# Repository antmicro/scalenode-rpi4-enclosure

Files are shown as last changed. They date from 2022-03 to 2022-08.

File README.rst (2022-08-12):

=========================
Scalenode RPi 4 enclosure
=========================

Copyright (c) 2022 `Antmicro <https://www.antmicro.com>`_

Overview
--------

This repository contains open hardware design files of the Raspberry Pi 4 cluster enclosure.

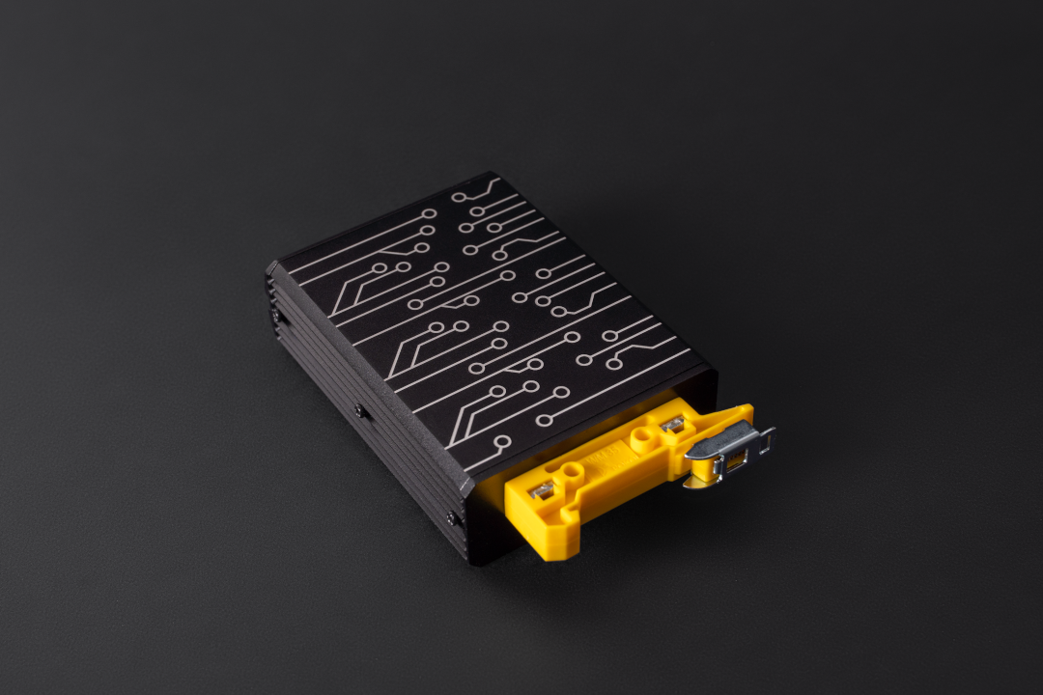
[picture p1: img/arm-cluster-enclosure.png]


It is designed to be a modular and stackable solution for an ARM cluster based on Raspberry Pi 4B. 
The design files are provided in a STEP file format.
The geometry of the metal body of the enclosure allows for machining with most of the CNC prototyping services.
The enclosure includes a translucent 3D-printable light guide which was optimized for SLA printing with translucent resins.

Repository structure
--------------------
The main repository directory contains 3D models of the enclosure assembly, a LICENSE and README.
The remaining files are stored in the following directories:

* ``pts`` - contains the project parts in separate files
* ``img`` - contains graphics for this README
* ``dwg`` - contains mechanical drawings
* ``csv`` - contains BOM

Key features
------------
* Passive cooling design
* DIN rail mount
* RGB LED indicator
* Modular and stackable
* 2U in a 19" rack cabinet
* Up to 56 units fit on a single floor of the rack cabinet

Mechanical outline
------------------

The enclosure provides passive cooling and was designed in a stackable form on a TH35 (DIN) rail.
There are multiple off-the-shelf DIN rail panel brackets available for 19" rack cabinets. 
The enclosure occupies 2U while installed in a rack cabinet.
Below there is a mechanical overview provided with outline dimensions provided in millimeters.

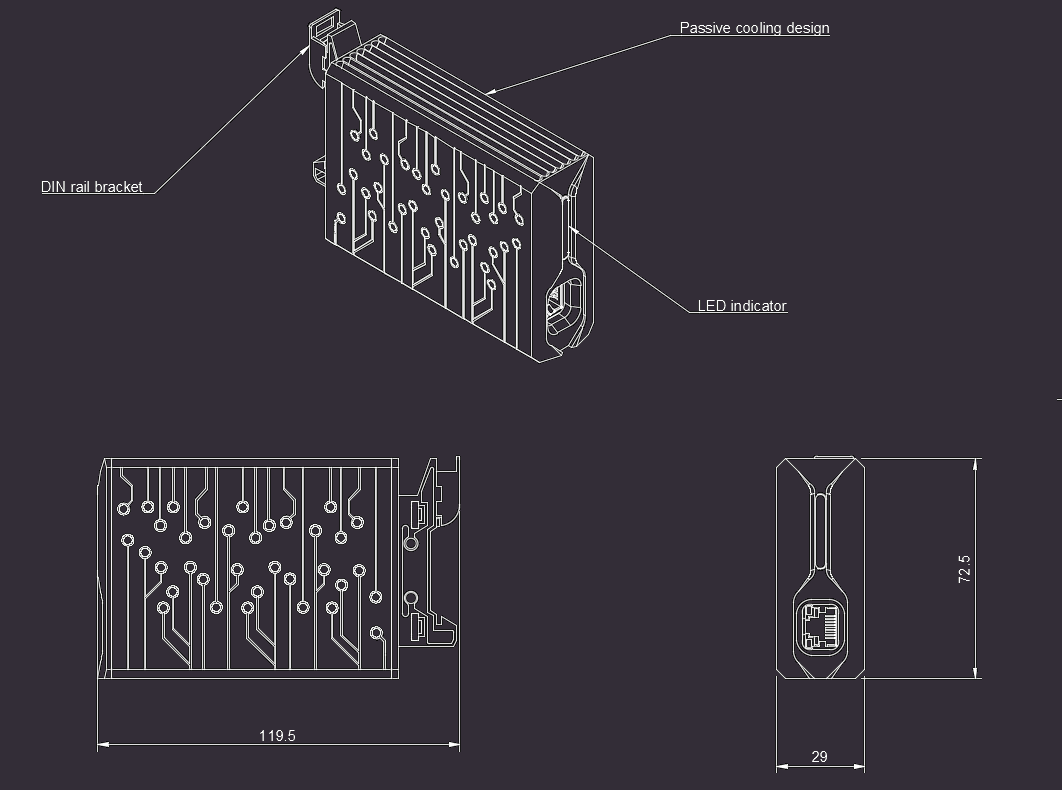
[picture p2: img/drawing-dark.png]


Assembly instructions
---------------------

A basic BOM is provided as a separate `CSV file <csv/rpi-enclosure-bom.csv>`_ to aid the component sourcing.
The assembly instructions below refer to the parts from that BOM.
The assembly includes a custom `RPi LED Flex PCB <https://github.com/antmicro/rpi-led-flex-board>`_ which has been released as an Open Source Hardware project in a separate repository.

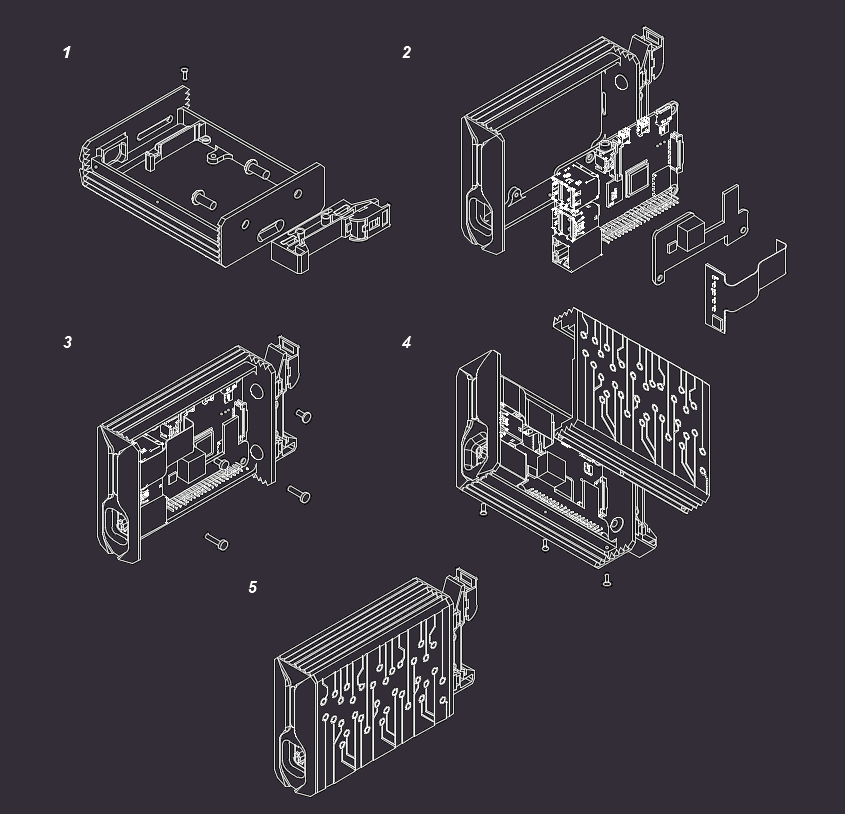
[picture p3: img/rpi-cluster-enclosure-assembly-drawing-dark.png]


#. Insert the 3D-printed RPi LED lightguide into the main case and fasten the bolt
   
   * Mount the WM-35 din clip with two bolts

#. Insert RPi LED indicator into the lightguide

   * Mount the UCTRONICS (`UC U6109 <https://www.uctronics.com/poe-hat-for-raspberry-pi-4-uctronics-mini-power-over-ethernet-expansion-board-for-raspberry-pi-4-b-3-b.html>`_) PoE hat on the Raspberry PI and put it in the main case
   * Insert FFC of the LED indicator into the camera connector (J3) located on the Raspberry Pi

#. Fasten Raspberry Pi and the PoE hat using M2.5 bolts

   * Apply some thermal paste to the processor and the DC/DC regulator on the PoE Hat

#. Put the cover on and press it down so that the paste evenly covers the surface of the ICs

   * Place the bolts in the holes on the bottom of the housing and tighten them gently
   
#. Insert an SD card to the Raspberry using a slot located under the DIN clip

#. Attach Ethernet cable connected to a PoE switch/injector and check if the RPi boots

License
=======

`Apache-2.0 <LICENSE>`_

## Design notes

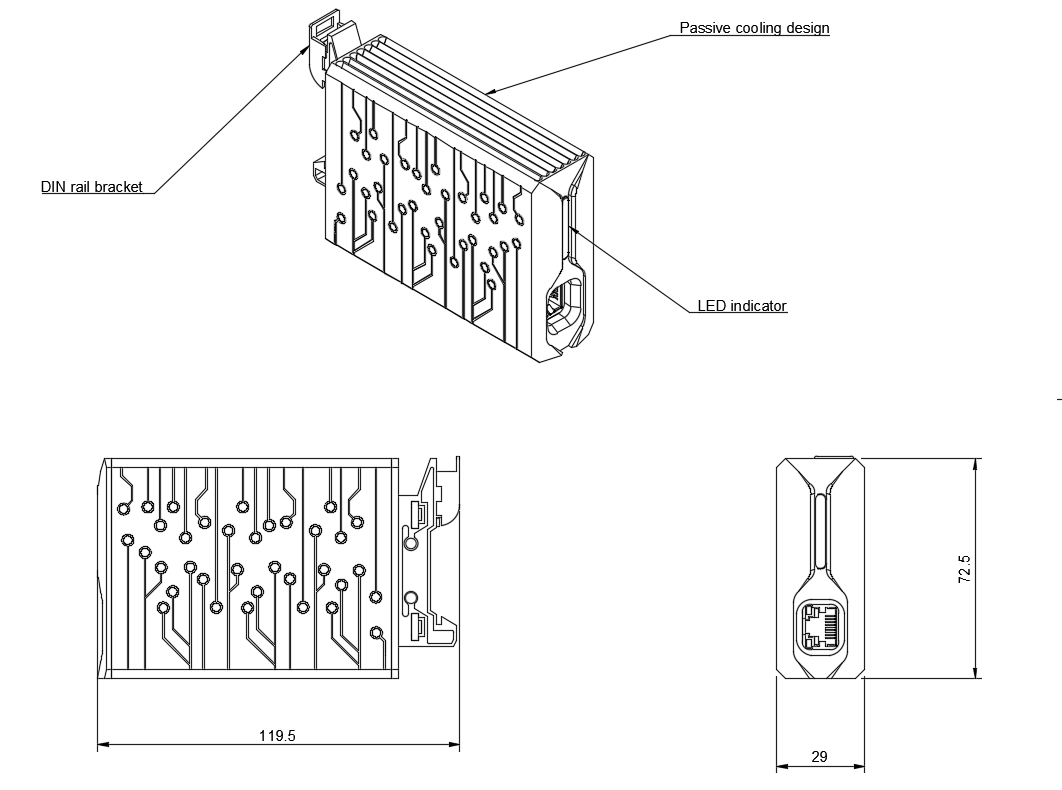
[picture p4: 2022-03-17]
img/drawing.png

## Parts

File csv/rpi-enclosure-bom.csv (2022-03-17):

Item | Description | Qty per unit
1 | RPi Enclosure | 1
2 | RPi LED lightguide | 1
3 | RPi LED Indicator | 1
4 | Raspberry Pi 4 B 8GB RAM 1.5GHz | 1
5 | PoE Hat UCTRONICS U6109 | 1
6 | WM-35 DIN clip | 1
7 | Enclosure fastening bolts(M1.6x5) | 3
8 | Lightguide fastening bolt (M1.6x5) | 1
9 | Poe Hat fastening bolts (M2.5x5) | 2
10 | RPi fastening bolts (M2.5x5) | 2
11 | DIN clip fastening bolts (M4x10) | 2
12 | PoE Hat standoff (2.7x03) | 2
13 | Thermal paste | 1g

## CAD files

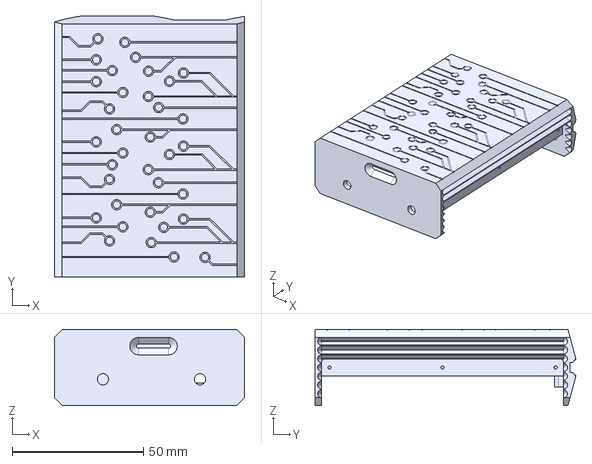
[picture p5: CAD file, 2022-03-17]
pts/rpi-cluster-enclosure-main-case.step
72.5 x 99.5 x 29.0 mm

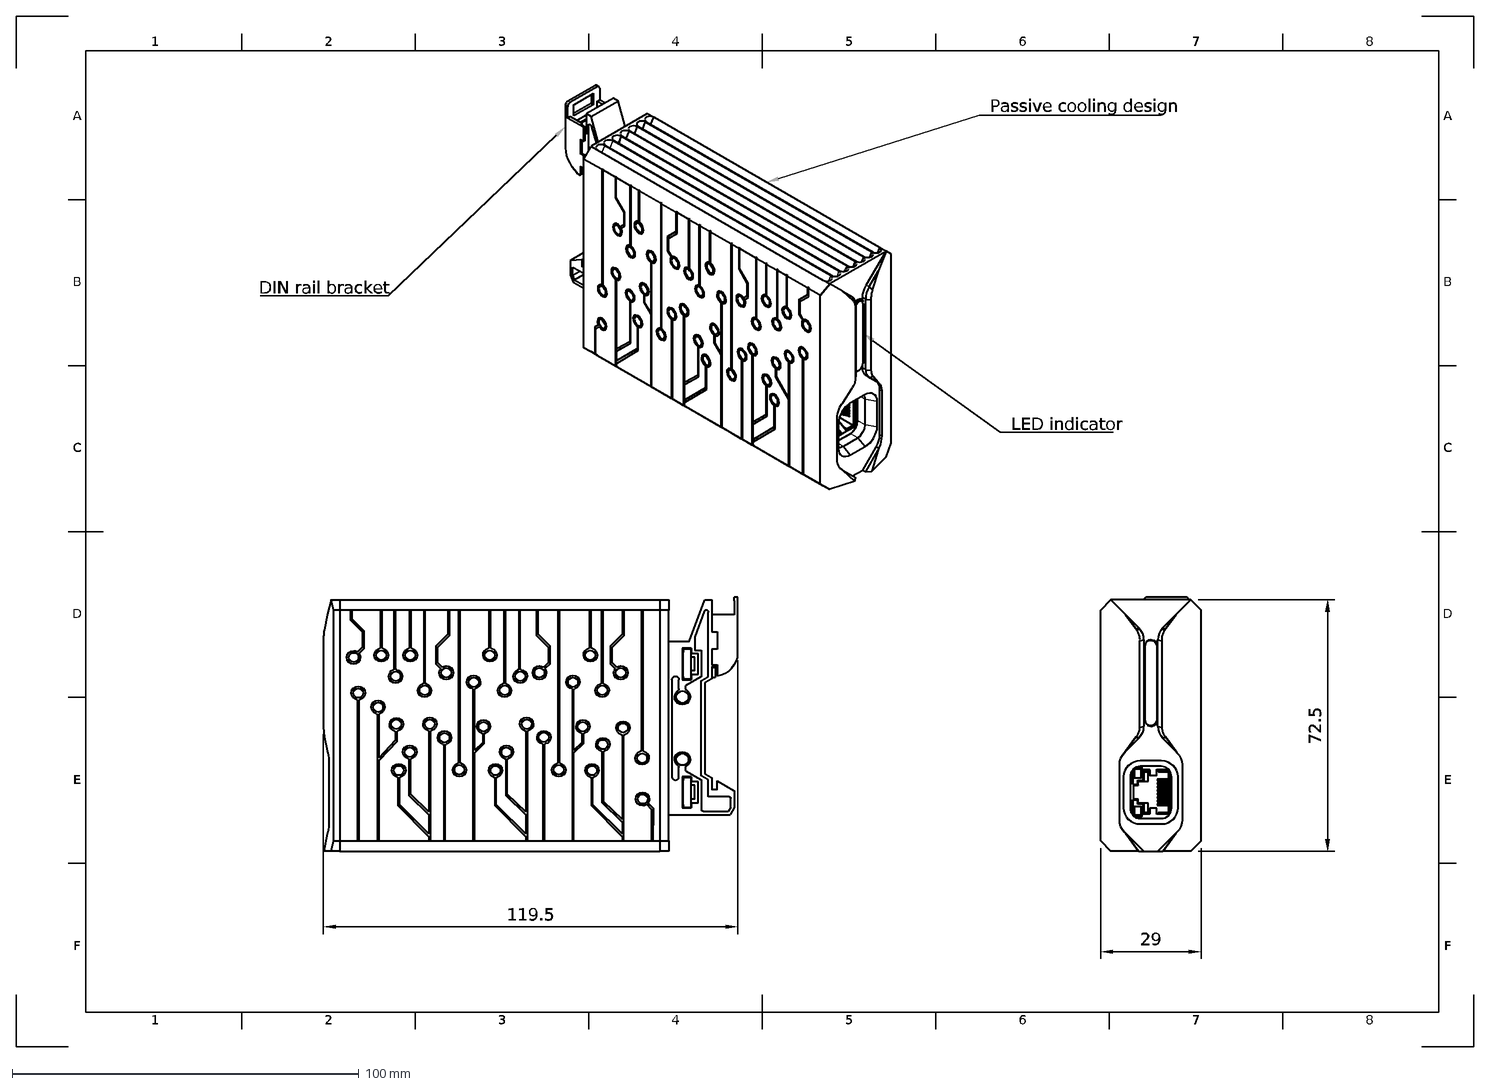
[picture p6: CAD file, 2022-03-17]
dwg/drawing.dxf
1
A
2
3
4
5
6
7
8
B
C
D
E
F
LED indicator
DIN rail bracket
Passive cooling design
119.5
29
72.5

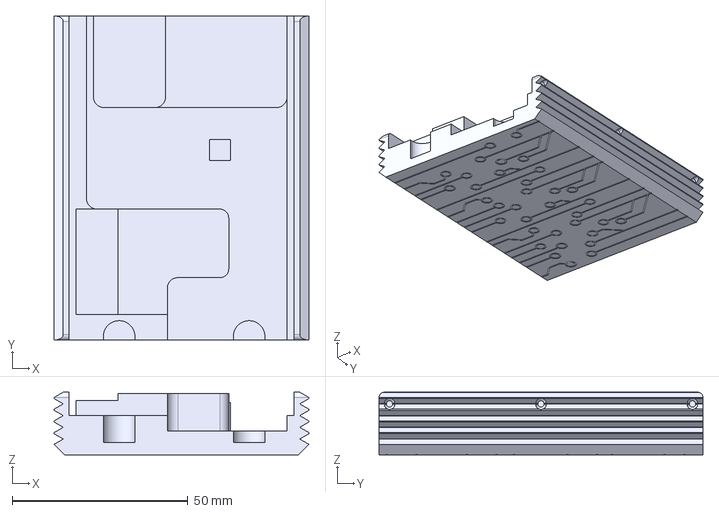
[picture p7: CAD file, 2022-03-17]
pts/rpi-cluster-enclosure-cover.step
72.5 x 92.2 x 17.8 mm

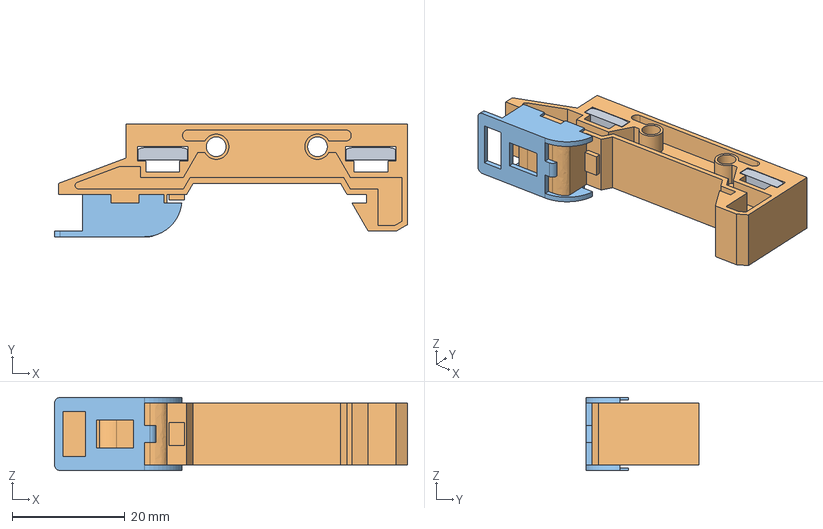
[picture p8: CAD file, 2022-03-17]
pts/wm-35-din-bracket.step
62.8 x 20.0 x 13.0 mm

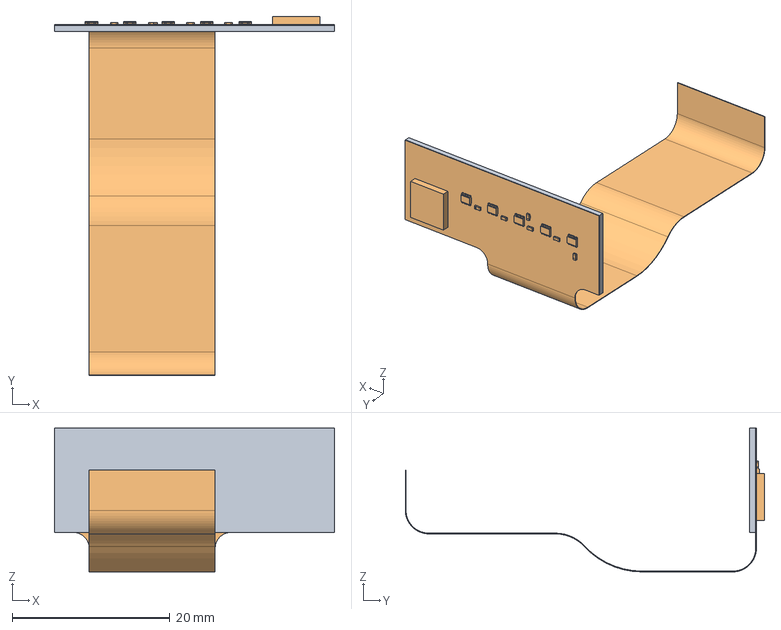
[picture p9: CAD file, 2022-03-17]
pts/rpi-led-indicator.step
35.5 x 45.6 x 18.3 mm

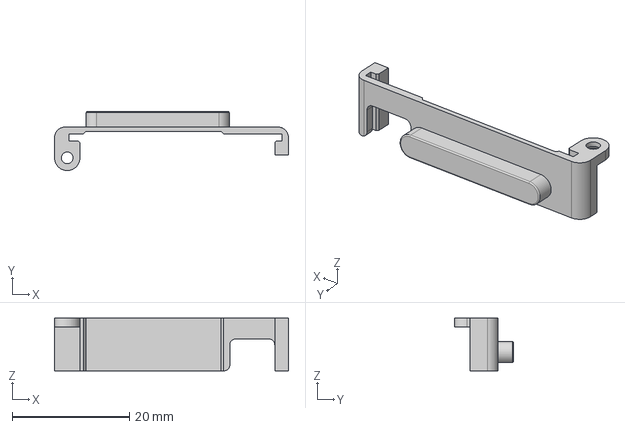
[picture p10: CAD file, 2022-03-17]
pts/rpi-cluster-enclosure-lightguide.step
40.0 x 10.1 x 9.00 mm

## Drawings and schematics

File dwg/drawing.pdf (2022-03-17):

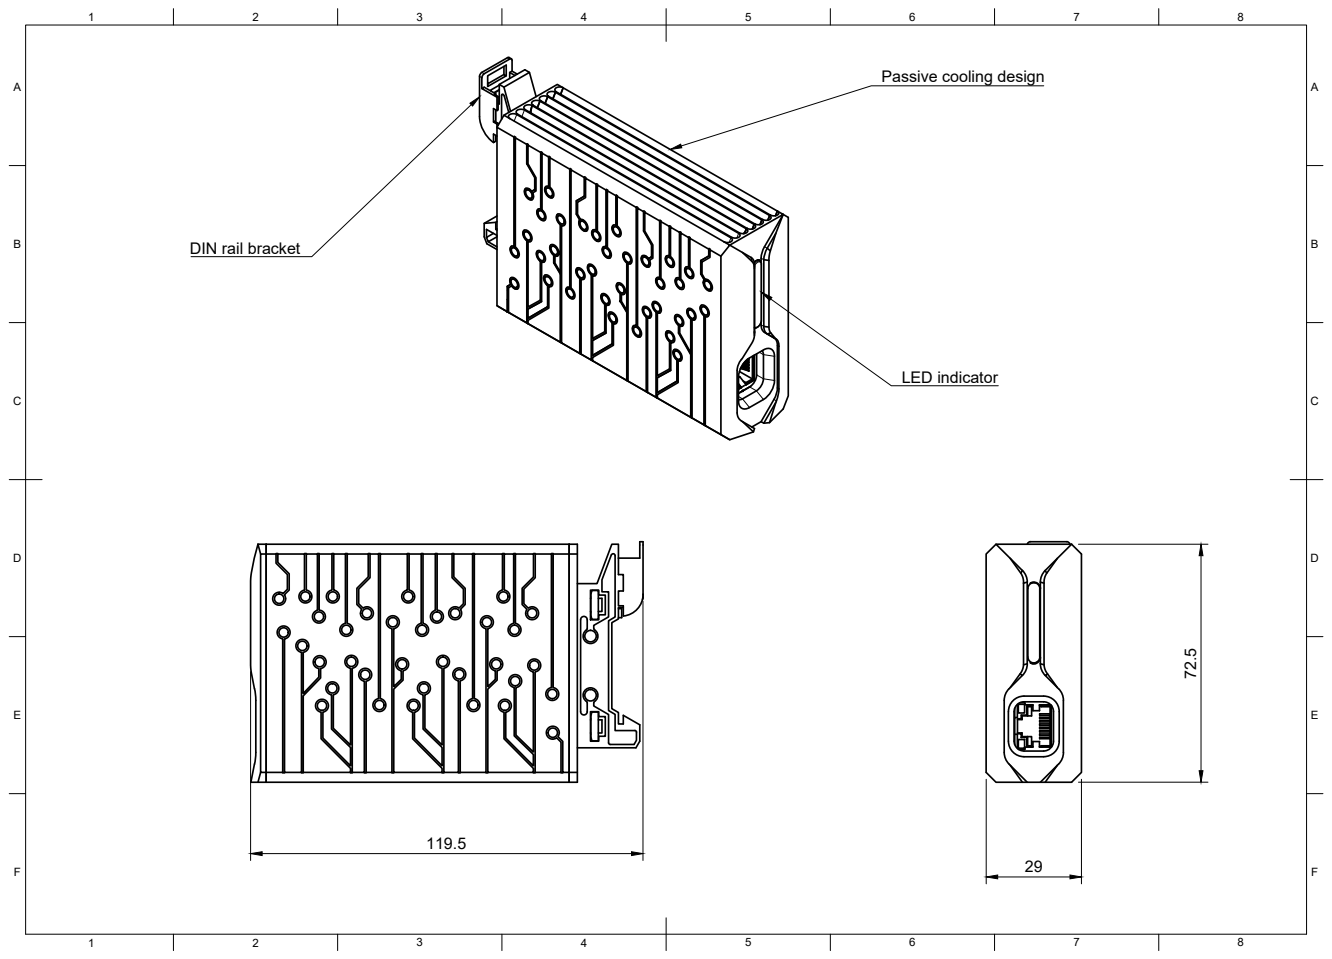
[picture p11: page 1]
LED indicator

Passive cooling design

DIN rail bracket

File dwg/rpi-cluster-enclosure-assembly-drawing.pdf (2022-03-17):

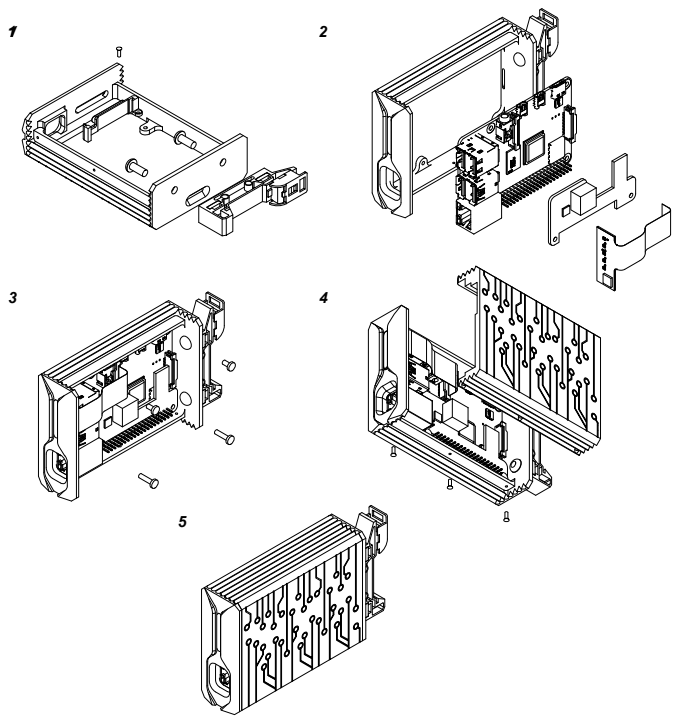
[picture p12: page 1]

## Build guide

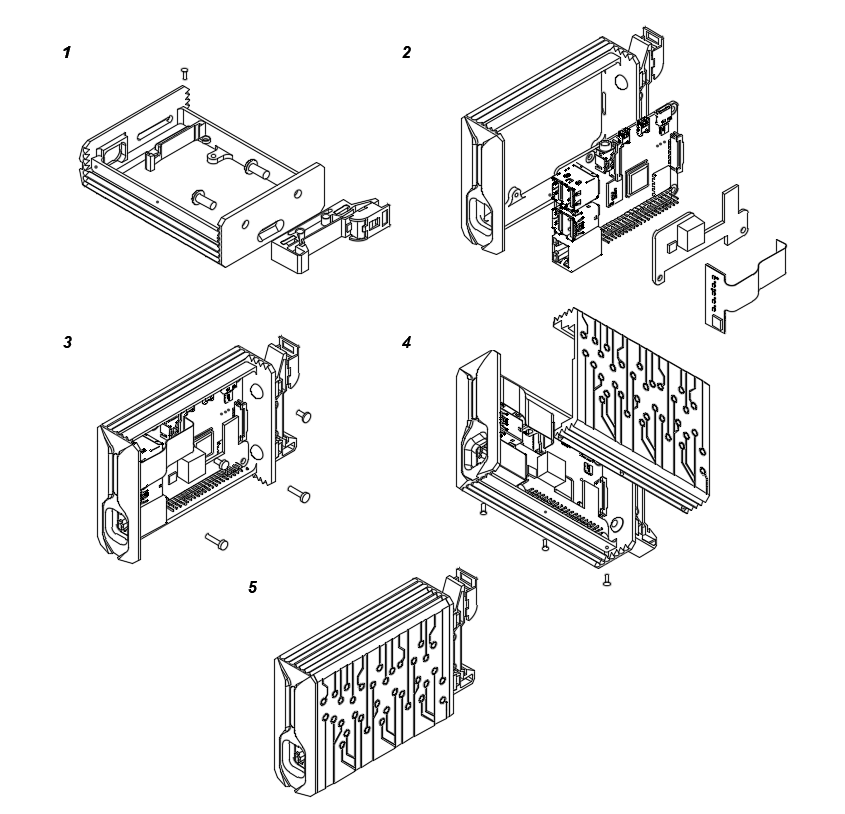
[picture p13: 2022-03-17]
img/rpi-cluster-enclosure-assembly-drawing.png

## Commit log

2022-03-17 Add initial design files
    [drawing.dxf, rpi-cluster-enclosure-cover.step, rpi-cluster-enclosure-lightguide.step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]
2022-03-17 Add Bill of materials
    [bom.csv]
2022-03-17 Add assembly instructions
2022-03-17 README: add link to the RPi LED Flex Board repository
